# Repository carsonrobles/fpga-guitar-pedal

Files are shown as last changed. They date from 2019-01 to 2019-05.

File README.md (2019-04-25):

# FPGA Multi-Effect Guitar Pedal
Carson Robles

## Project Description
This project strives to implement a multi-effect guitar pedal using an FPGA for all of the signal processing.

### Status
In development.

### Goal
The goal of this project is to take the place of multiple separate traditional guitar pedals each with its own dedicated effect.

## Effects
Below is a list of the currently working effects followed by a list of effects that are in development or are planned for future development.

### Working Effects
- Delay
- Distortion (variable gain hard clipping)
- Flanger
- Tremolo

### Effects in Development or Planned for the Future
- Wah Wah
- Phaser

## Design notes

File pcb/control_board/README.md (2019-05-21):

# FPGA Multi-Effect Guitar Pedal
Carson Robles

## Control Board
The main function of this board is to hold all components of the project including: the FPGA board, the data converter module, control knobs, foot switches, and enable LEDs.

### Status
In fabrication.

## Board Images
### Power System Schematic
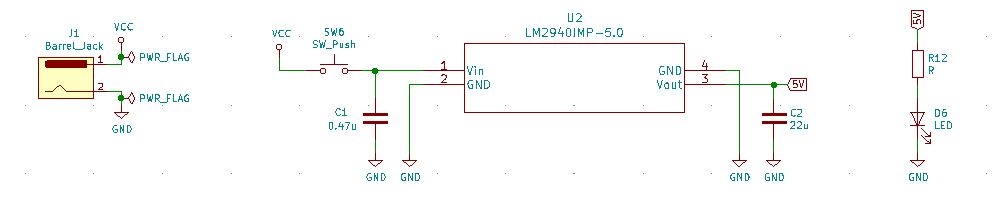
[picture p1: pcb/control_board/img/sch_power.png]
Power System

Schematic of the power supply that the system runs on. The board accepts 12V in through the onboard barrel jack and produces a regulated 5V supply to power the entire system.

### Effect Enables and Settings Schematic
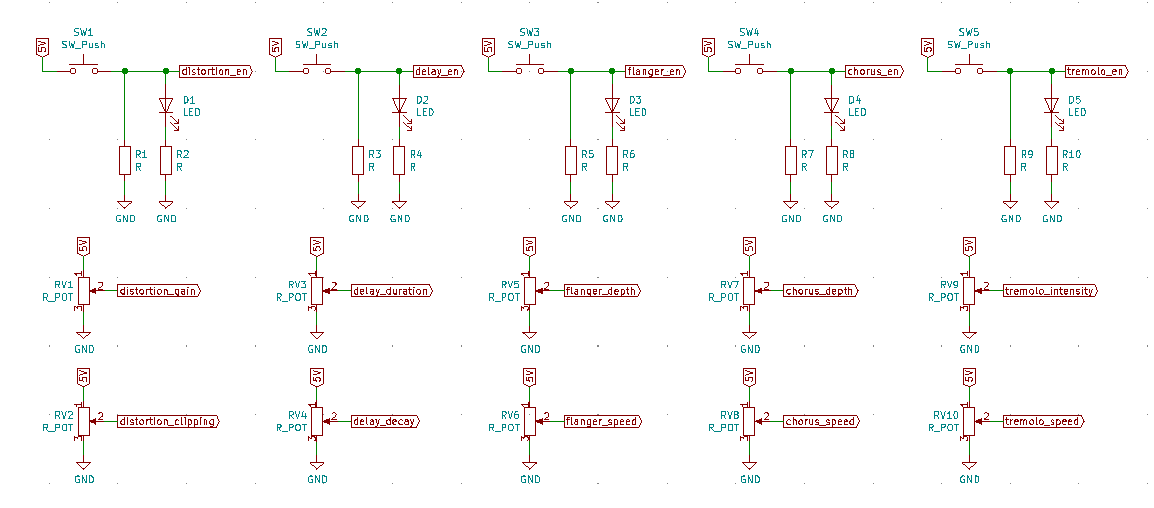
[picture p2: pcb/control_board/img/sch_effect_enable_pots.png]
Effect Settings and Enables

Schematic of the effect enables and settings potentiometers. These include the 5 foot switches used to enable and disable individual effects. Each effect also includes 2 potentiometer knobs that allow the user to modify each effect to their liking.

### FPGA Board Connections and Analog Mux Schematic
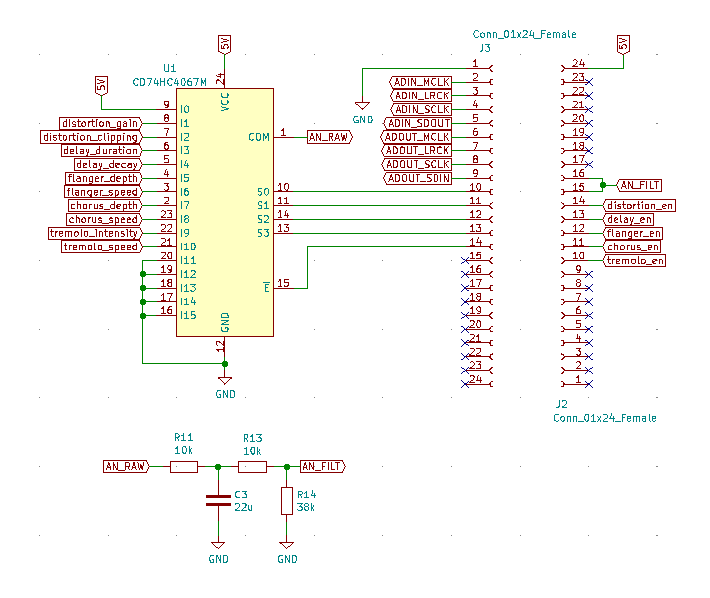
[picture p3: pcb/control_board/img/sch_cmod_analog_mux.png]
FPGA Board and Analog Mux

The FPGA is mounted onto the control board via 2 24 pin headers. The analog mux allows only one potentiometer voltage to pass at a time that the FPGA can read using its onboard ADC. The FPGA cycles through which potentiometer value it reads and updates its saved values when a new value is read. The output of the analog mux is filtered and divided down to the range that the onboard ADC can handle, 3.3V.

### Data Converter Module Connections
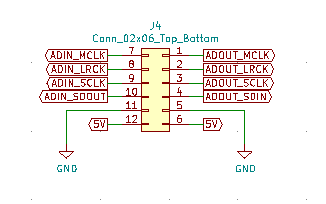
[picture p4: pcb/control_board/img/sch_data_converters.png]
Data Converter Module

The data converter module is also mounted to the control board via a Digilent PMOD header (2x6 pin header). This header is routed to I/O pins on the FPGA.

### Front of Board Layout
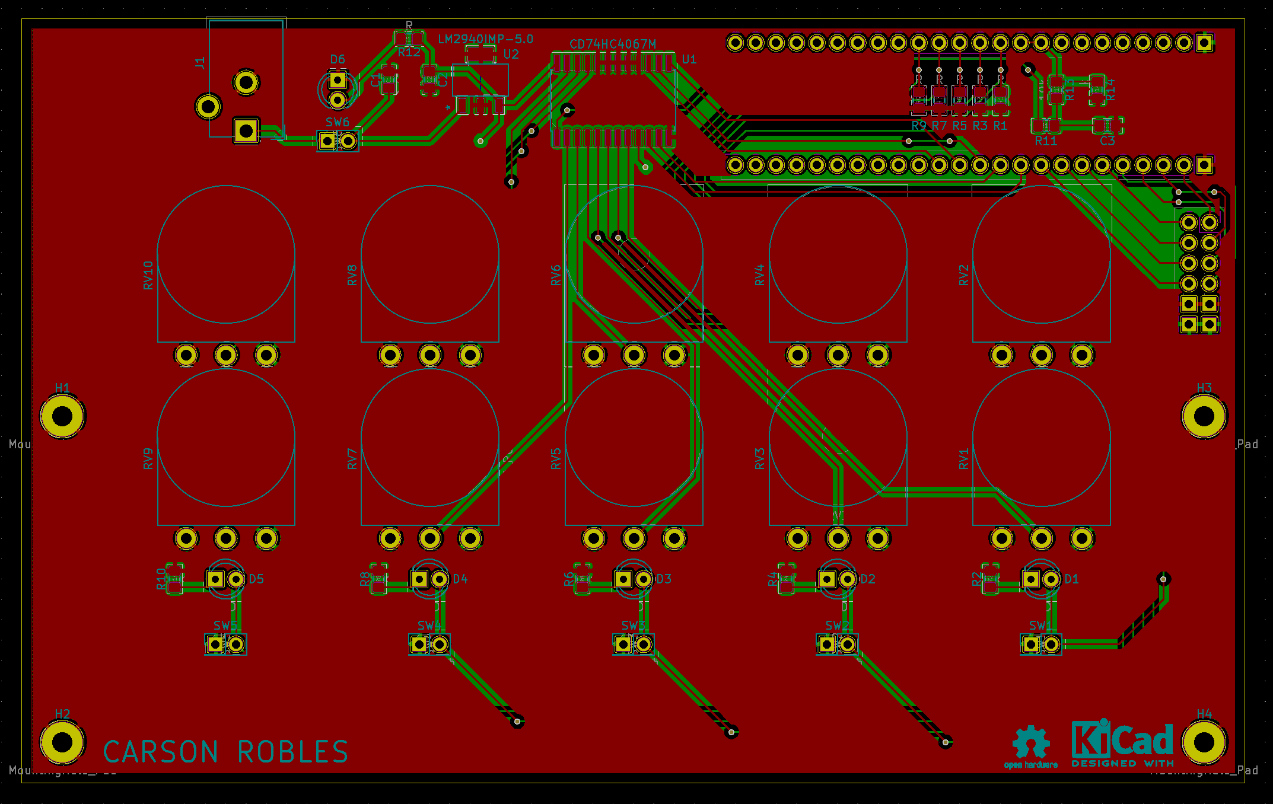
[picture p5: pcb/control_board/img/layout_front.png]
Layout Front


### Back of Board Layout
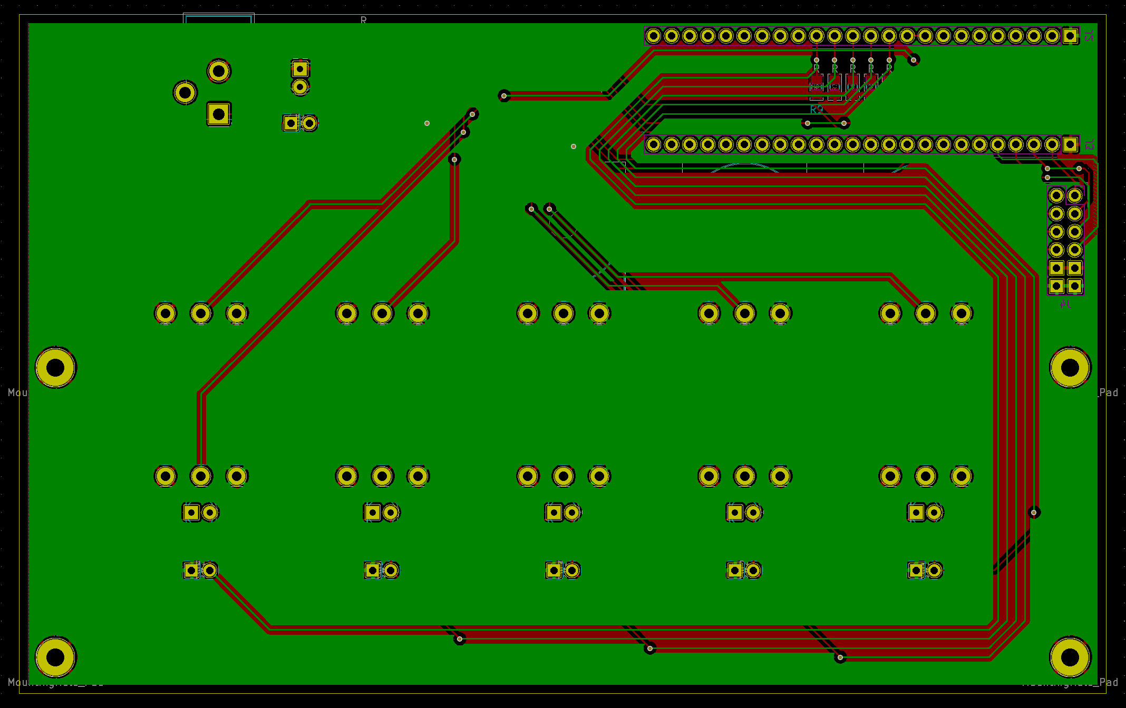
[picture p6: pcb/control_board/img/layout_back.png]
Layout Back


### Front of Board Rendering
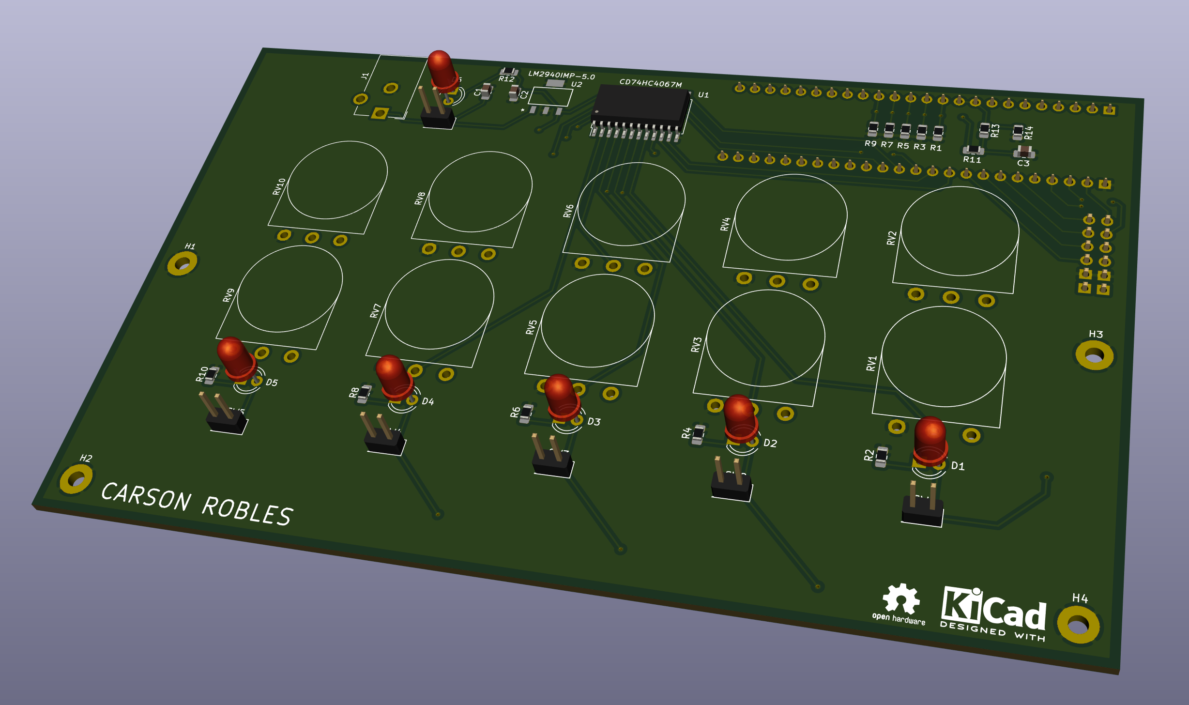
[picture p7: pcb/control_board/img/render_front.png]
Render Front


### Back of Board Rendering
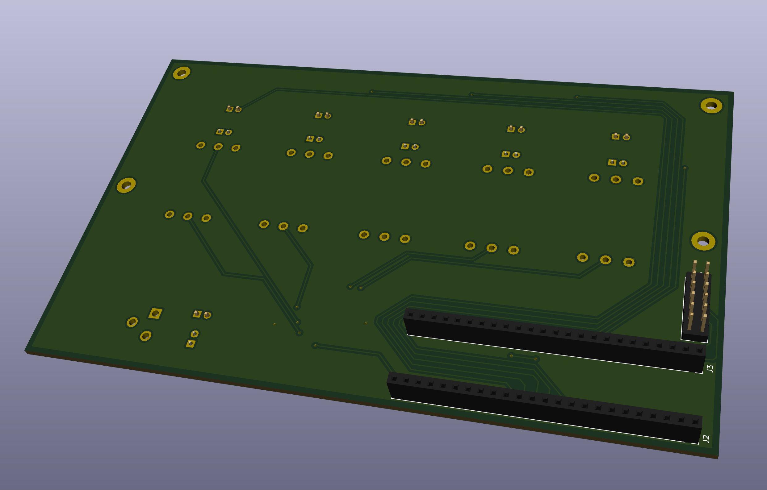
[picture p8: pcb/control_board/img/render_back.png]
Render Back


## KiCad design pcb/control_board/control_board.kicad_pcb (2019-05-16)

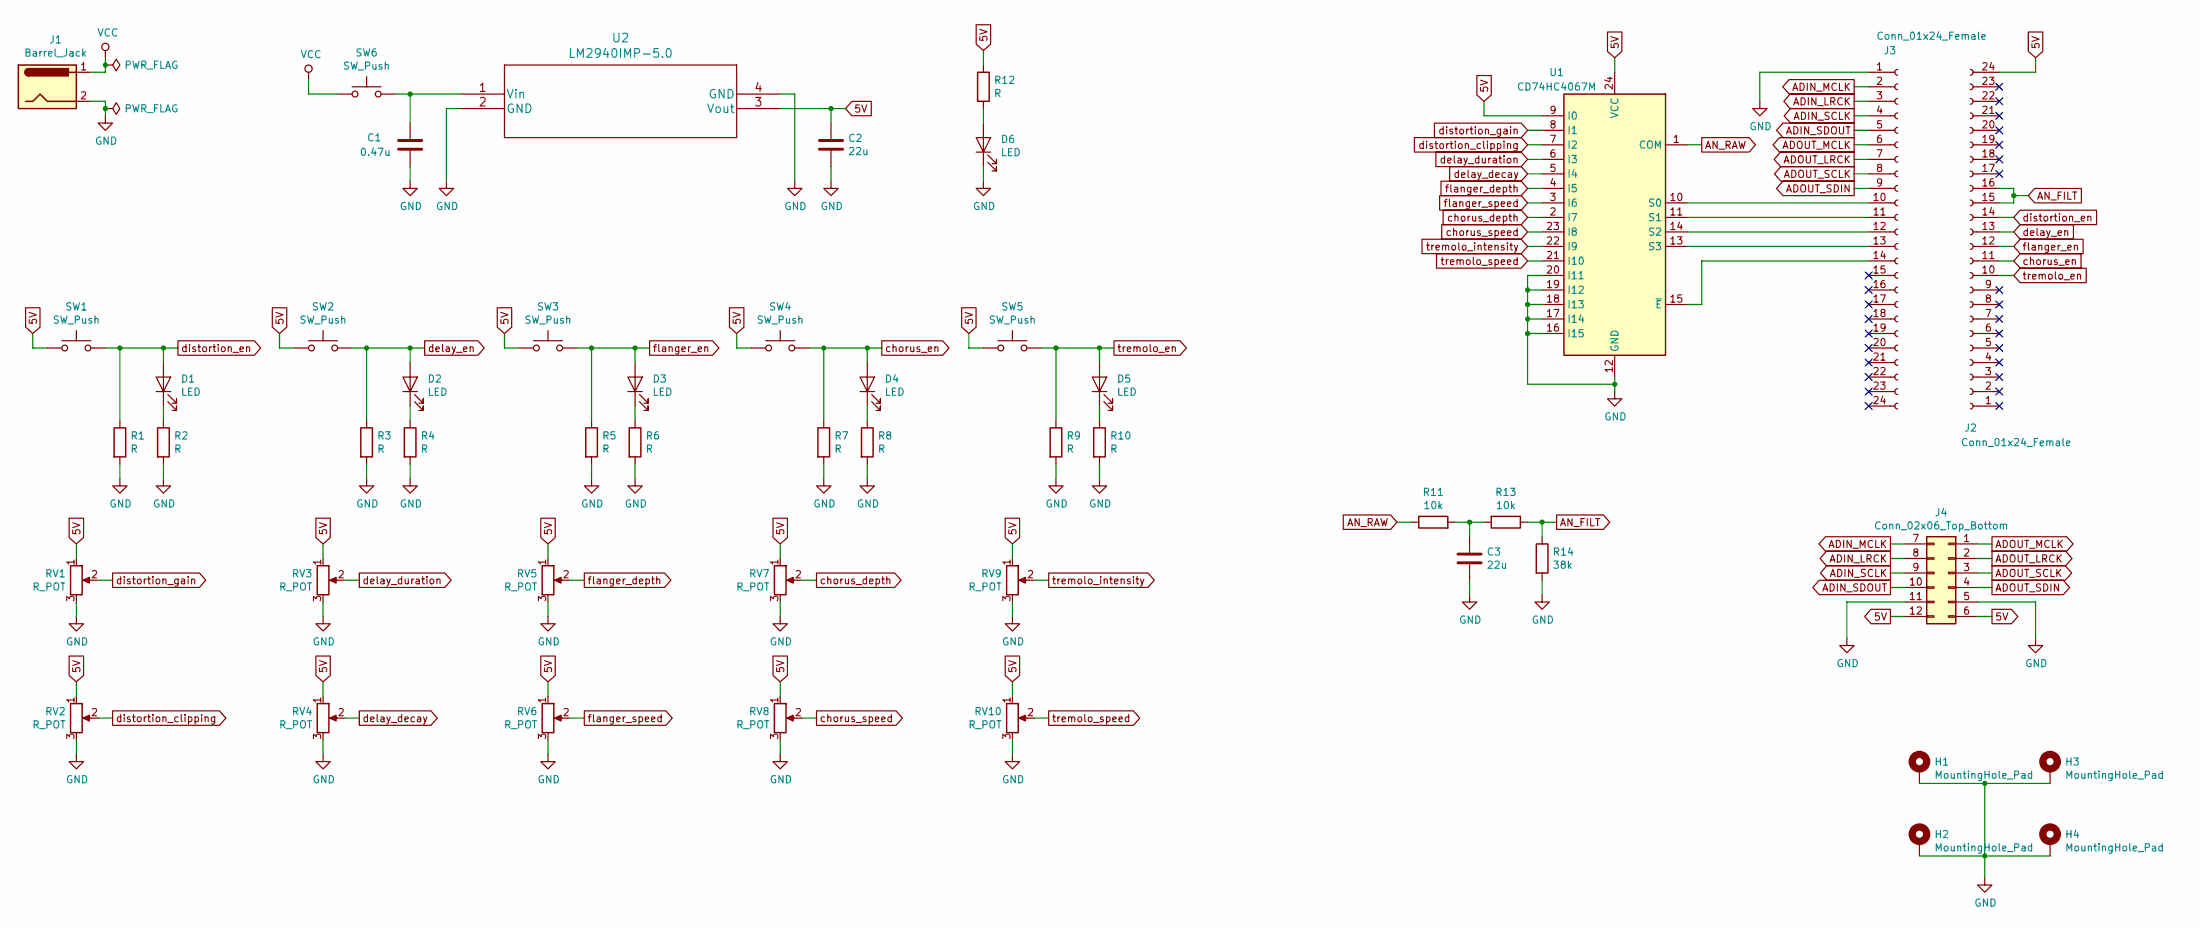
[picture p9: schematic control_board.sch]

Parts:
C1: 0.47u; C_0805_2012Metric_Pad1.15x1.40mm_HandSolder
C2, C3: 22u; C_0805_2012Metric_Pad1.15x1.40mm_HandSolder
D1, D2, D3, D4, D5, D6: LED; LED_D4.0mm
H1, H2, H3, H4: MountingHole_Pad; MountingHole_2.5mm_Pad
J1: Barrel_Jack; BarrelJack_CUI_PJ-102AH_Horizontal
J2, J3: Conn_01x24_Female; PinSocket_1x24_P2.54mm_Vertical
J4: Conn_02x06_Top_Bottom; PinHeader_2x06_P2.54mm_Vertical
R1, R2, R3, R4, R5, R6, R7, R8, R9, R10, R12: R; R_0805_2012Metric_Pad1.15x1.40mm_HandSolder
R11, R13: 10k; R_0805_2012Metric_Pad1.15x1.40mm_HandSolder
R14: 38k; R_0805_2012Metric_Pad1.15x1.40mm_HandSolder
RV1, RV2, RV3, RV4, RV5, RV6, RV7, RV8, RV9, RV10: R_POT; Potentiometer_Omeg_PC16BU_Vertical
SW1, SW2, SW3, SW4, SW5, SW6: SW_Push; PinHeader_2x01_P2.54mm_Vertical
U1: CD74HC4067M; SOIC-24W_7.5x15.4mm_P1.27mm
U2: LM2940IMP-5.0

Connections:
5V: C2.1, J2.24, J4.6, J4.12, R12.1, RV1.1, RV2.1, RV3.1, RV4.1, RV5.1, RV6.1, RV7.1, RV8.1, RV9.1, RV10.1, SW1.1, SW2.1, SW3.1, SW4.1, SW5.1, U1.9 (I0), U1.24 (VCC), U2.3 (Vout)
ADIN_LRCK: J3.3, J4.8
ADIN_MCLK: J3.2, J4.7
ADIN_SCLK: J3.4, J4.9
ADIN_SDOUT: J3.5, J4.10
ADOUT_LRCK: J3.7, J4.2
ADOUT_MCLK: J3.6, J4.1
ADOUT_SCLK: J3.8, J4.3
ADOUT_SDIN: J3.9, J4.4
AN_FILT: J2.15, J2.16, R13.1, R14.1
AN_RAW: R11.1, U1.1 (COM)
GND: C1.2, C2.2, C3.2, D6.1 (K), H1.1, H2.1, H3.1, H4.1, J1.2, J3.1, J4.5, J4.11, R1.2, R2.2, R3.2, R4.2, R5.2, R6.2, R7.2, R8.2, R9.2, R10.2, R14.2, RV1.3, RV2.3, RV3.3, RV4.3, RV5.3, RV6.3, RV7.3, RV8.3, RV9.3, RV10.3, U1.12 (GND), U1.16 (I15), U1.17 (I14), U1.18 (I13), U1.19 (I12), U1.20 (I11), U2.2 (GND), U2.4 (GND)
unnamed: C1.1, SW6.2, U2.1 (Vin)
unnamed: C3.1, R11.2, R13.2
unnamed: D1.1 (K), R2.1
unnamed: D2.1 (K), R4.1
unnamed: D3.1 (K), R6.1
unnamed: D4.1 (K), R8.1
unnamed: D5.1 (K), R10.1
unnamed: D6.2 (A), R12.2
unnamed: J3.10, U1.10 (S0)
unnamed: J3.11, U1.11 (S1)
unnamed: J3.12, U1.14 (S2)
unnamed: J3.13, U1.13 (S3)
unnamed: J3.14, U1.15 (~E)
VCC: J1.1, SW6.1
chorus_depth: RV7.2, U1.2 (I7)
chorus_en: D4.2 (A), J2.11, R7.1, SW4.2
chorus_speed: RV8.2, U1.23 (I8)
delay_decay: RV4.2, U1.5 (I4)
delay_duration: RV3.2, U1.6 (I3)
delay_en: D2.2 (A), J2.13, R3.1, SW2.2
distortion_clipping: RV2.2, U1.7 (I2)
distortion_en: D1.2 (A), J2.14, R1.1, SW1.2
distortion_gain: RV1.2, U1.8 (I1)
flanger_depth: RV5.2, U1.4 (I5)
flanger_en: D3.2 (A), J2.12, R5.1, SW3.2
flanger_speed: RV6.2, U1.3 (I6)
tremolo_en: D5.2 (A), J2.10, R9.1, SW5.2
tremolo_intensity: RV9.2, U1.22 (I9)
tremolo_speed: RV10.2, U1.21 (I10)

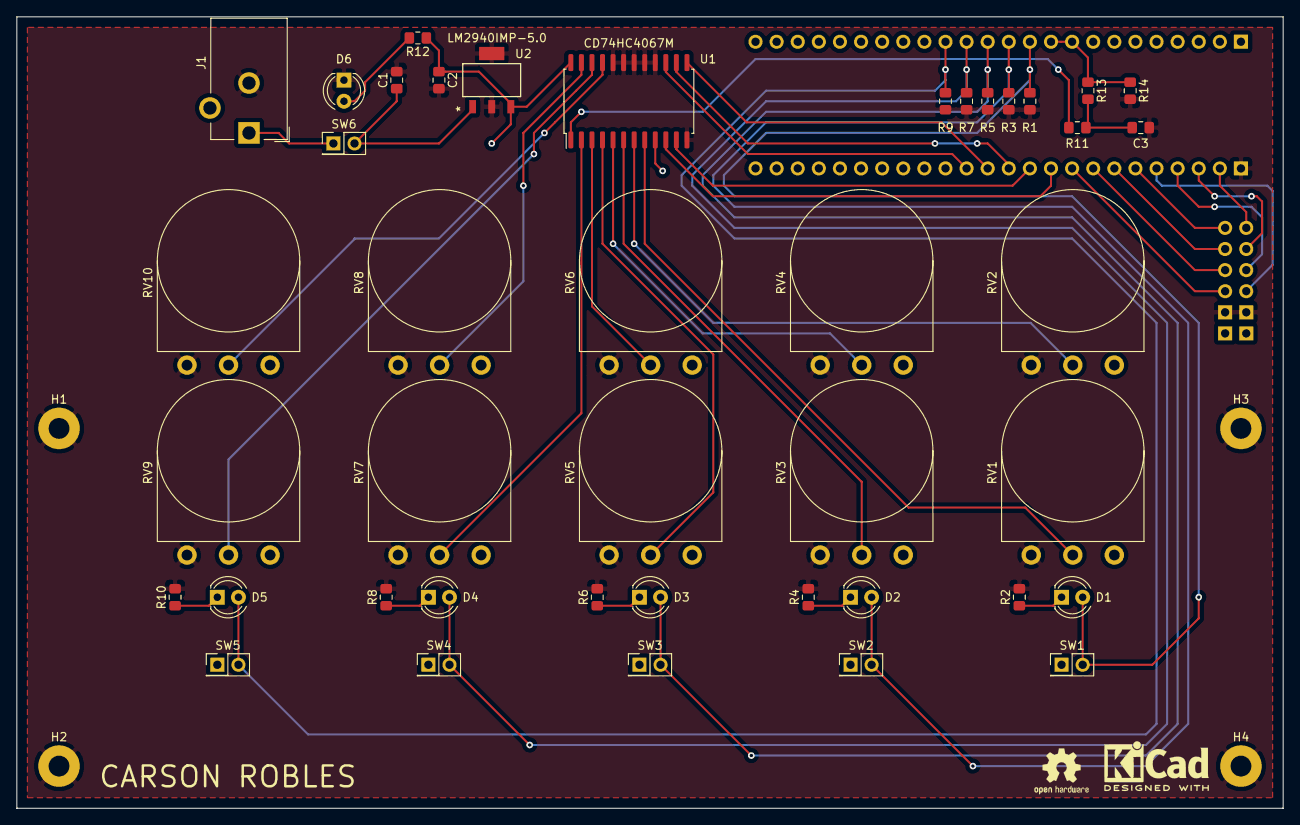
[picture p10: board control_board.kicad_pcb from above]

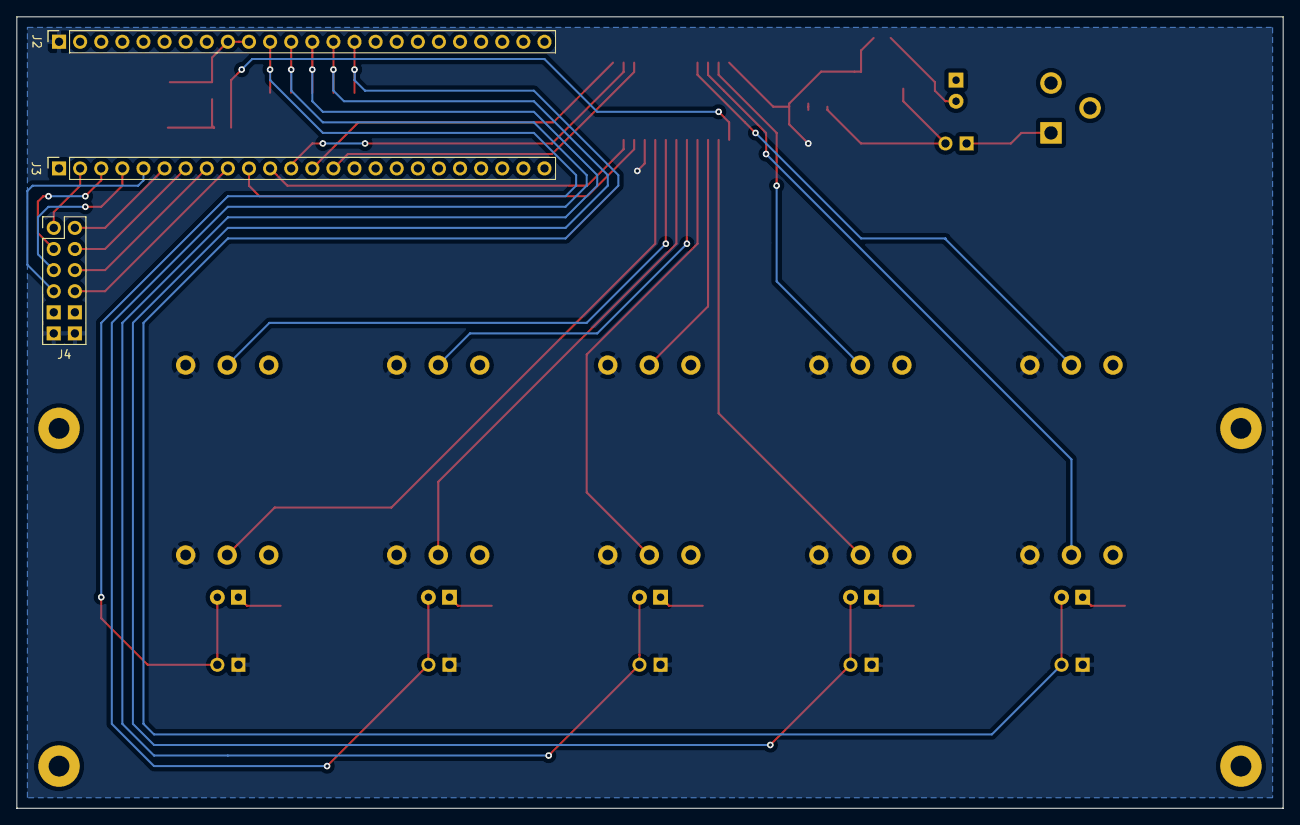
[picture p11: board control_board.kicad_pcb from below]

Board: 2 copper layers, 152.4 x 95.2 mm, 49 parts (3 on the bottom side), 41 nets.

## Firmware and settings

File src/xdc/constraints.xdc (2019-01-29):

## Clock signal
##Bank = 35, Pin name = IO_L12P_T1_MRCC_35,					Sch name = CLK100MHZ
set_property PACKAGE_PIN E3 [get_ports FPGA_CLK_100]							
	set_property IOSTANDARD LVCMOS33 [get_ports FPGA_CLK_100]
	create_clock -add -name sys_clk_pin -period 10.00 -waveform {0 5} [get_ports FPGA_CLK_100]
 
## Switches
##Bank = 34, Pin name = IO_L21P_T3_DQS_34,					Sch name = SW0
set_property PACKAGE_PIN U9 [get_ports {SW[0]}]					
	set_property IOSTANDARD LVCMOS33 [get_ports {SW[0]}]
##Bank = 34, Pin name = IO_25_34,							Sch name = SW1
set_property PACKAGE_PIN U8 [get_ports {SW[1]}]					
	set_property IOSTANDARD LVCMOS33 [get_ports {SW[1]}]
##Bank = 34, Pin name = IO_L23P_T3_34,						Sch name = SW2
set_property PACKAGE_PIN R7 [get_ports {SW[2]}]					
	set_property IOSTANDARD LVCMOS33 [get_ports {SW[2]}]
##Bank = 34, Pin name = IO_L19P_T3_34,						Sch name = SW3
set_property PACKAGE_PIN R6 [get_ports {SW[3]}]					
	set_property IOSTANDARD LVCMOS33 [get_ports {SW[3]}]
##Bank = 34, Pin name = IO_L19N_T3_VREF_34,					Sch name = SW4
set_property PACKAGE_PIN R5 [get_ports {SW[4]}]					
	set_property IOSTANDARD LVCMOS33 [get_ports {SW[4]}]
##Bank = 34, Pin name = IO_L20P_T3_34,						Sch name = SW5
set_property PACKAGE_PIN V7 [get_ports {SW[5]}]					
	set_property IOSTANDARD LVCMOS33 [get_ports {SW[5]}]
##Bank = 34, Pin name = IO_L20N_T3_34,						Sch name = SW6
set_property PACKAGE_PIN V6 [get_ports {SW[6]}]					
	set_property IOSTANDARD LVCMOS33 [get_ports {SW[6]}]
##Bank = 34, Pin name = IO_L10P_T1_34,						Sch name = SW7
set_property PACKAGE_PIN V5 [get_ports {SW[7]}]					
	set_property IOSTANDARD LVCMOS33 [get_ports {SW[7]}]
##Bank = 34, Pin name = IO_L8P_T1-34,						Sch name = SW8
set_property PACKAGE_PIN U4 [get_ports {SW[8]}]					
	set_property IOSTANDARD LVCMOS33 [get_ports {SW[8]}]
##Bank = 34, Pin name = IO_L9N_T1_DQS_34,					Sch name = SW9
set_property PACKAGE_PIN V2 [get_ports {SW[9]}]					
	set_property IOSTANDARD LVCMOS33 [get_ports {SW[9]}]
##Bank = 34, Pin name = IO_L9P_T1_DQS_34,					Sch name = SW10
set_property PACKAGE_PIN U2 [get_ports {SW[10]}]					
	set_property IOSTANDARD LVCMOS33 [get_ports {SW[10]}]
##Bank = 34, Pin name = IO_L11N_T1_MRCC_34,					Sch name = SW11
set_property PACKAGE_PIN T3 [get_ports {SW[11]}]					
	set_property IOSTANDARD LVCMOS33 [get_ports {SW[11]}]
##Bank = 34, Pin name = IO_L17N_T2_34,						Sch name = SW12
set_property PACKAGE_PIN T1 [get_ports {SW[12]}]					
	set_property IOSTANDARD LVCMOS33 [get_ports {SW[12]}]
##Bank = 34, Pin name = IO_L11P_T1_SRCC_34,					Sch name = SW13
set_property PACKAGE_PIN R3 [get_ports {SW[13]}]					
	set_property IOSTANDARD LVCMOS33 [get_ports {SW[13]}]
##Bank = 34, Pin name = IO_L14N_T2_SRCC_34,					Sch name = SW14
set_property PACKAGE_PIN P3 [get_ports {SW[14]}]					
	set_property IOSTANDARD LVCMOS33 [get_ports {SW[14]}]
##Bank = 34, Pin name = IO_L14P_T2_SRCC_34,					Sch name = SW15
set_property PACKAGE_PIN P4 [get_ports {SW[15]}]					
	set_property IOSTANDARD LVCMOS33 [get_ports {SW[15]}]
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

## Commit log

2019-02-01 Remove AXI handshake interface and replace with just a valid flag. This should be just fine since there should never be a situation where there is back pressure because this would imply the sampling 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
2019-02-03 Modify effects pipe to use only left channel of full audio sample.
2019-02-19 Update Makefile to have program target and program tcl script to program board.
2019-02-28 Change RGB module reset to reset button rather than synchronized reset (to mclk) to avoid failed timing.
2019-02-28 Add python tool to print warnings and error from all stages of compilation after a complete build.
2019-05-13 First revision of control board complete.
    [chorus_control.sch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]
2019-05-13 Remove unused protoype directory.
    [chorus_control.sch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]
2019-05-15 Correctly place CMOD headers, add divider to filter to drop potentiometer voltage into range of CMOD ADC.
    [control_board.kicad_pcb, control_board.sch]
2019-05-15 Add connectors for switches rather than holes for direct wires.
    [control_board.kicad_pcb, control_board.sch]
2019-05-16 Final board changes.
    [control_board-B_Cu.gbl, control_board-B_Mask.gbs, control_board-B_Paste.gbp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]
2019-05-16 Update gitignore remove old effects schematics.
    [chorus_control.sch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]
2019-05-16 Add README to control board directory.

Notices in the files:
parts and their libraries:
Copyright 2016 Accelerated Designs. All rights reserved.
